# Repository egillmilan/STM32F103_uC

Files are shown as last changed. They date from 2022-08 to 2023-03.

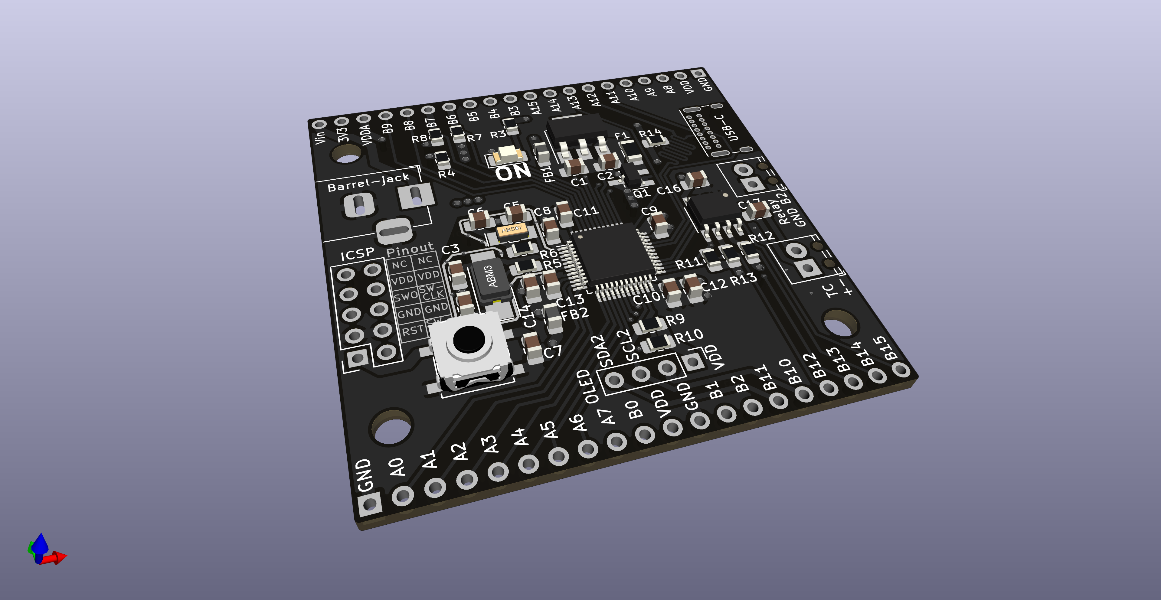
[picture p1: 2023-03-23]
STM32F103_uC_v1/images/STM32F103_uC_v1_1.png

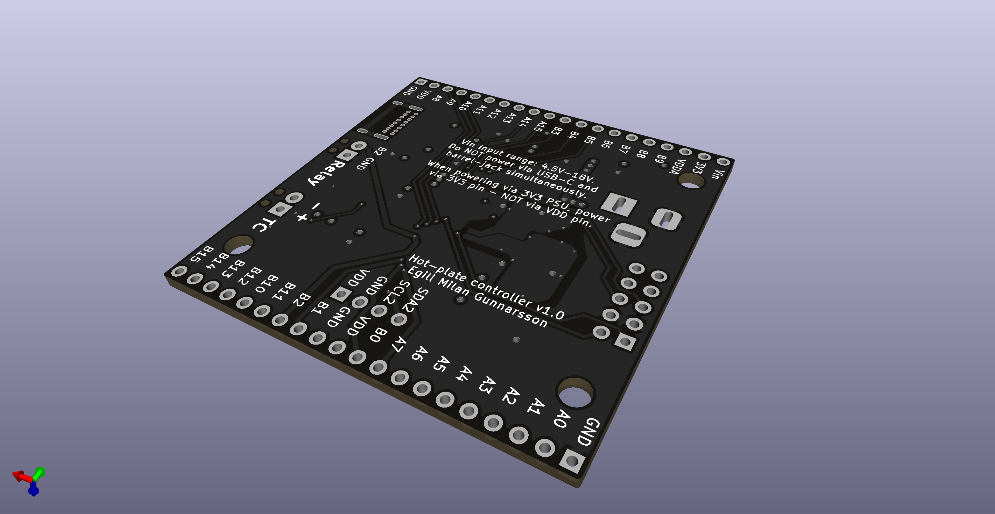
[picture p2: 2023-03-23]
STM32F103_uC_v1/images/STM32F103_uC_v1_2.png

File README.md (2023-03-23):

# STM32F103_uC
 A control board for a reflow hot plate project. The microcontroller being used is the STM32F103C8T6.

STM32F103_uC_v1_4
STM32F103_uC_v1_3
STM32F103_uC_v1_1
STM32F103_uC_v1_2

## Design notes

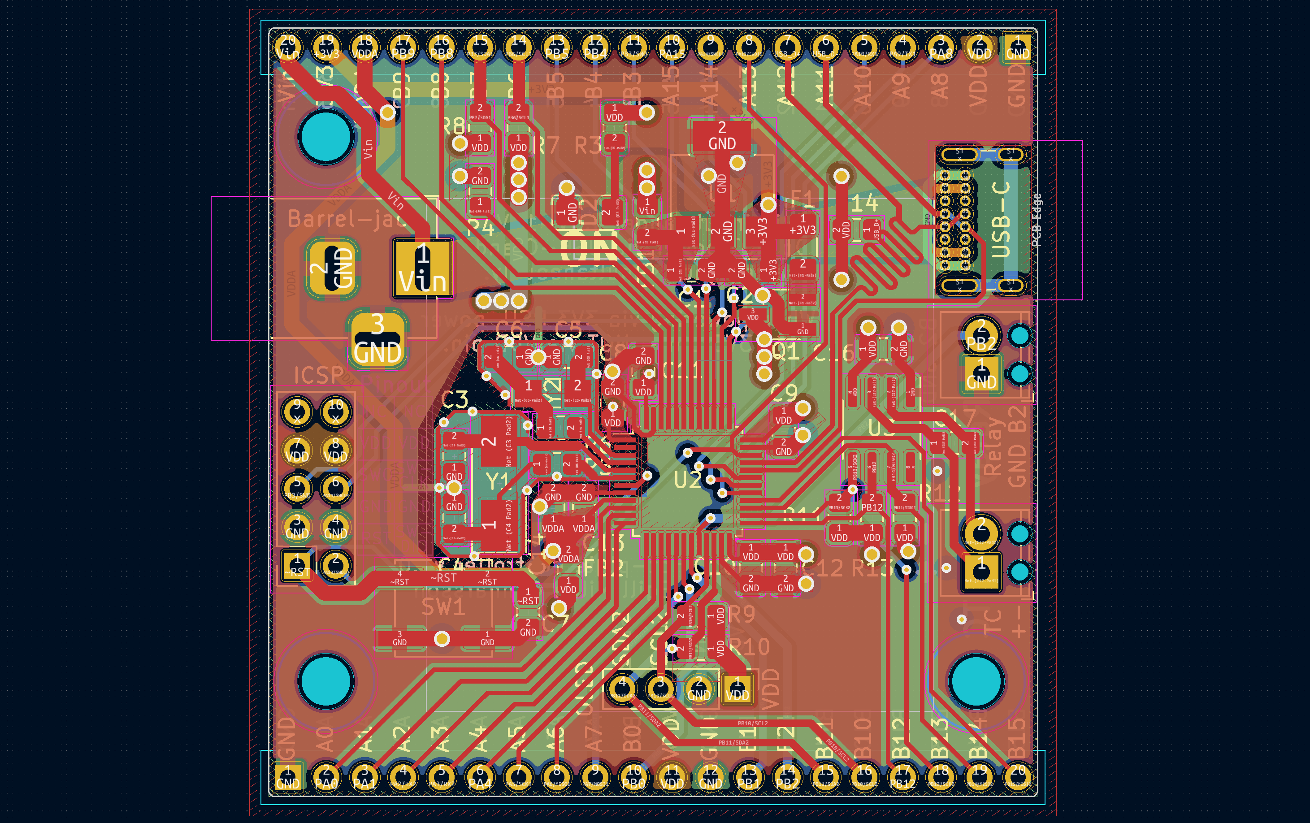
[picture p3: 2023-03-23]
STM32F103_uC_v1/images/STM32F103_uC_v1_3.png

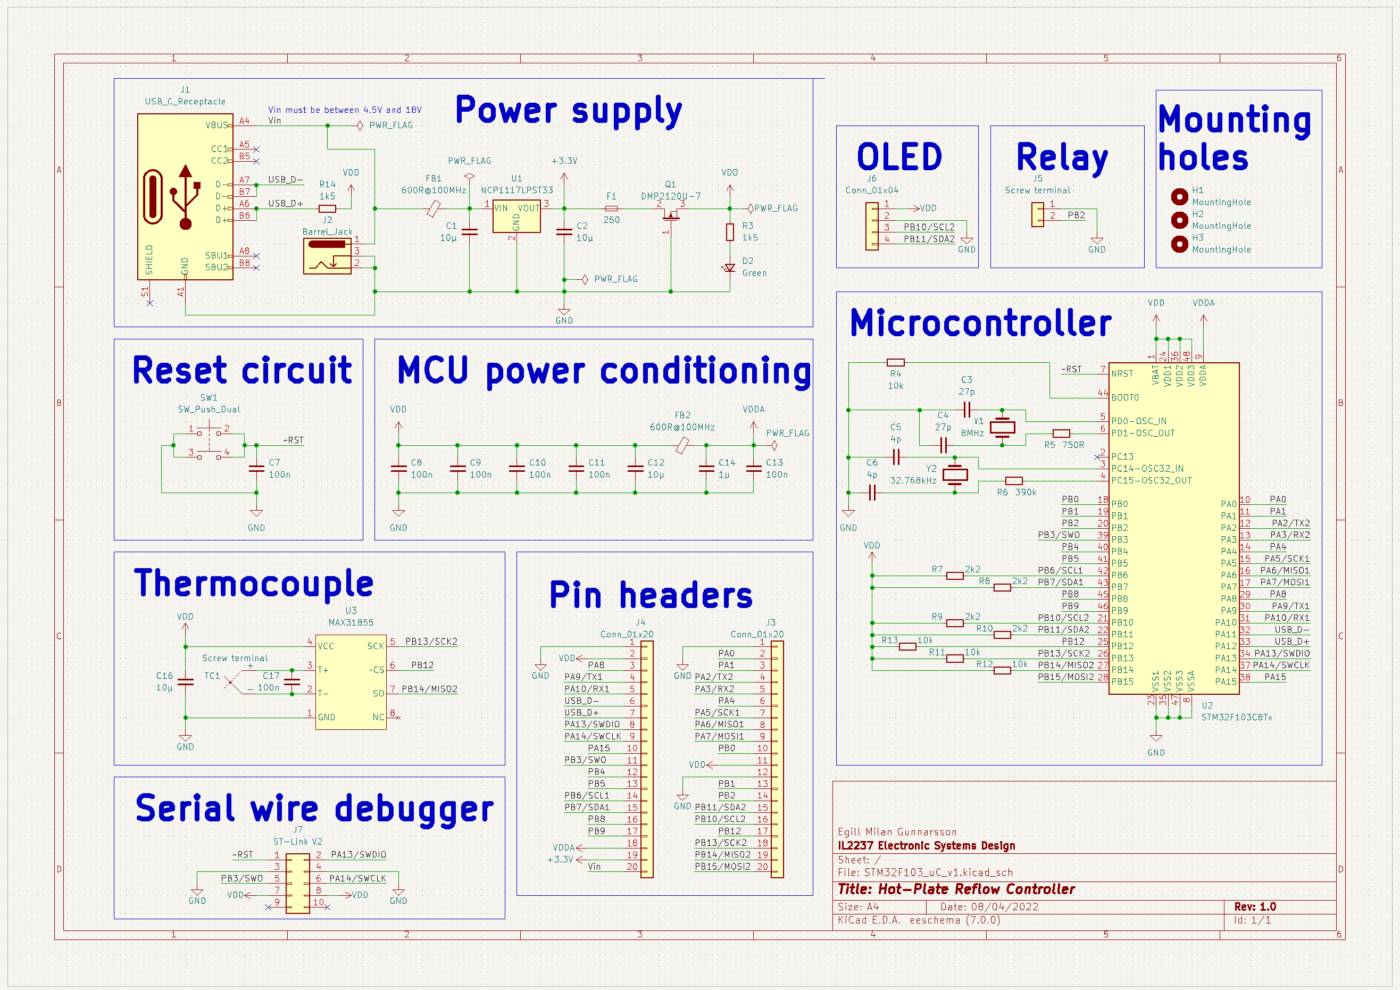
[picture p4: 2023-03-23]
STM32F103_uC_v1/images/STM32F103_uC_v1_4.png

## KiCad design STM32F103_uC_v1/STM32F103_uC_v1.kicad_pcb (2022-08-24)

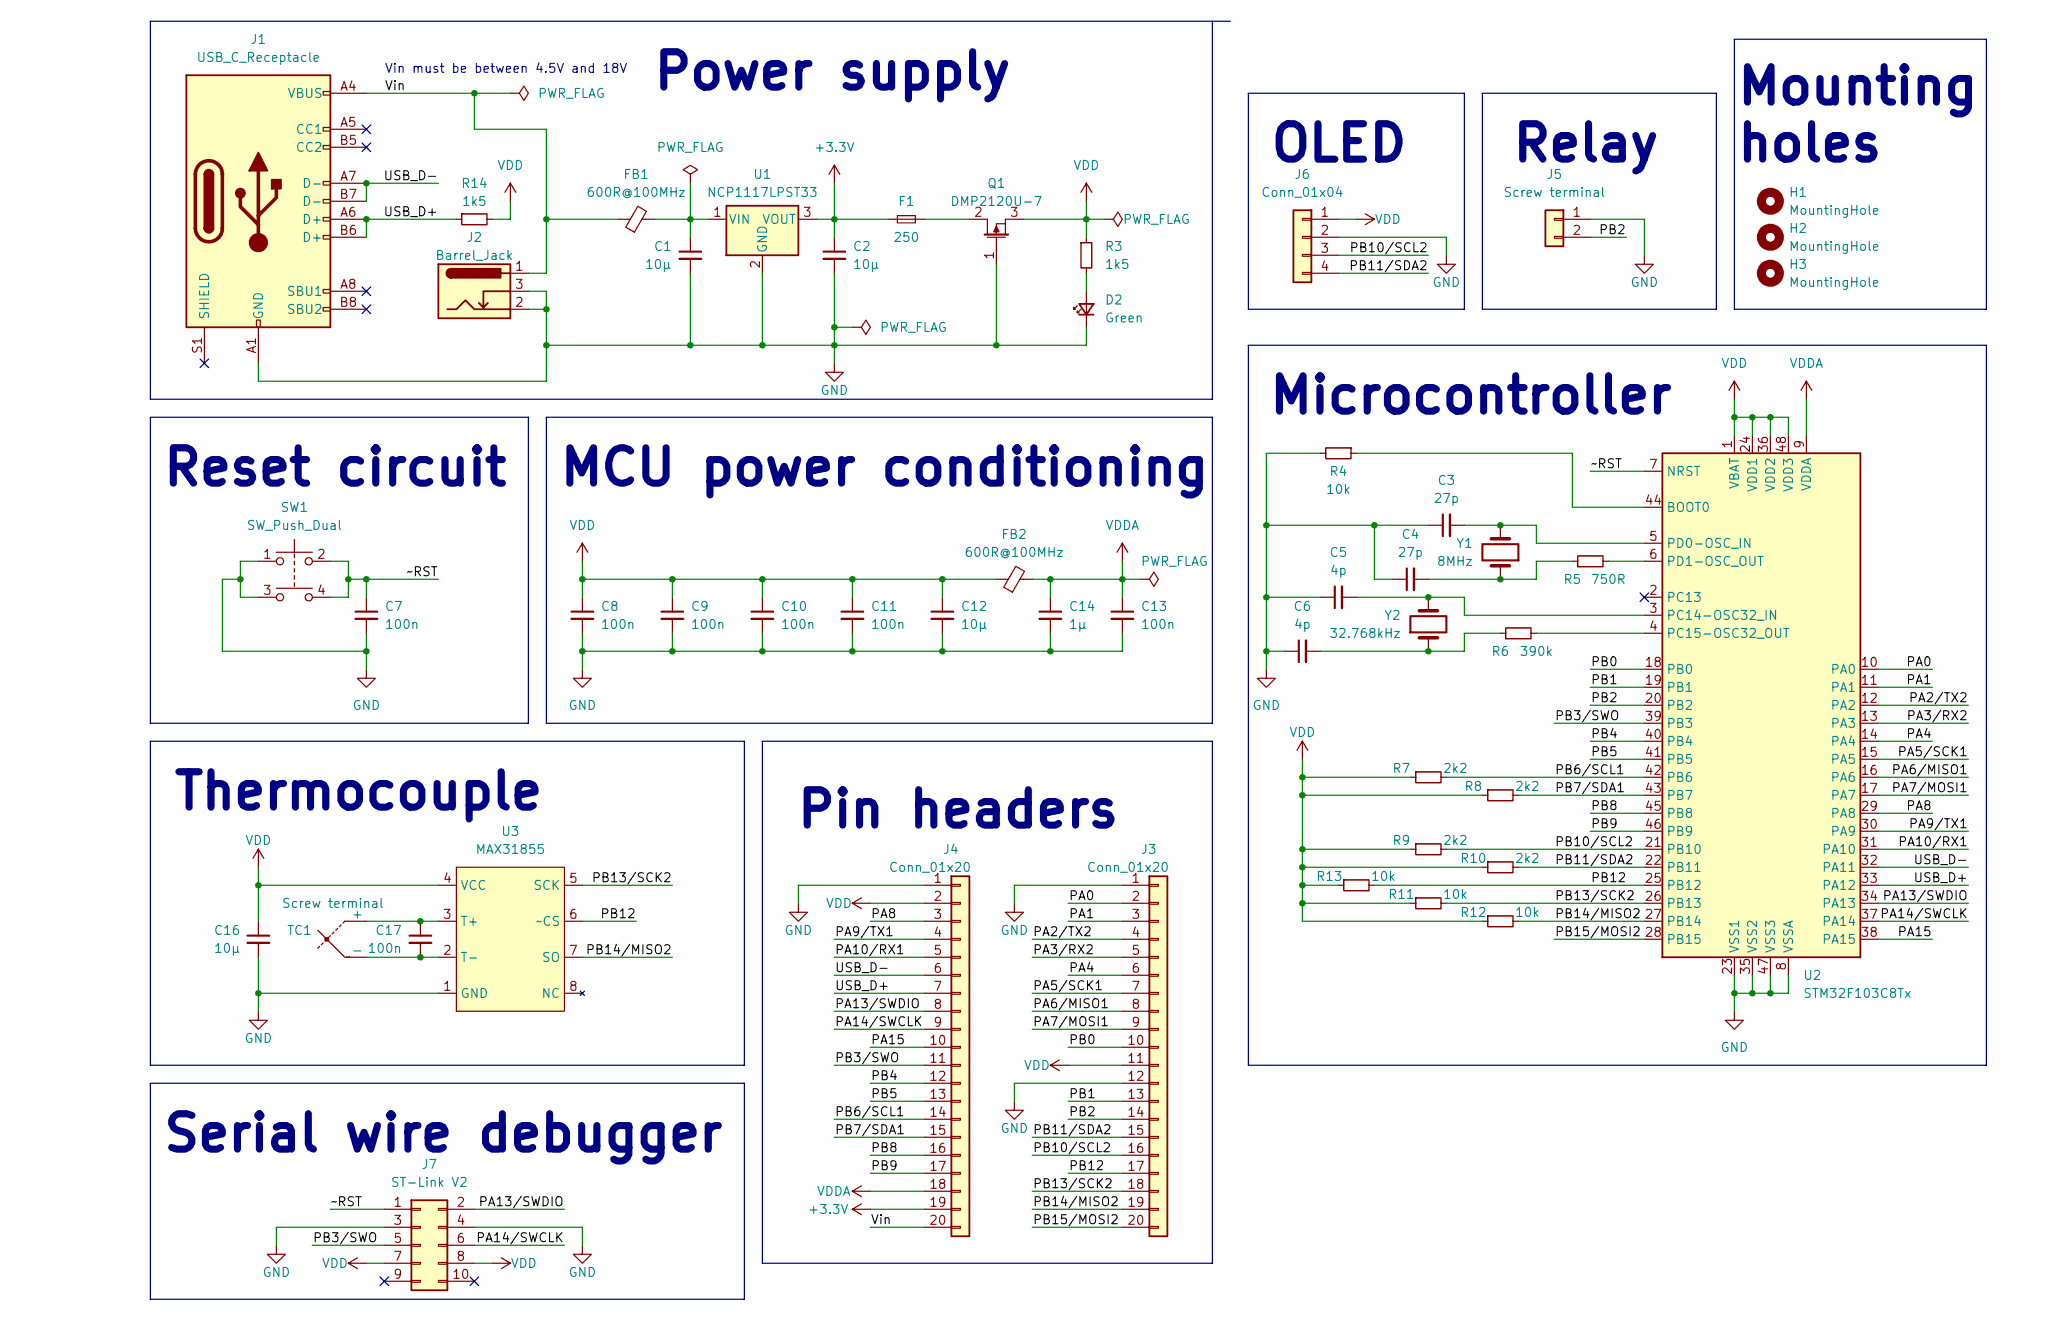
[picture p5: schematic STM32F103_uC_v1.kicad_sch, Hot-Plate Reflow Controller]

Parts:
C1, C2, C12, C16: 10µ; C_0805_2012Metric_Pad1.18x1.45mm_HandSolder
C3, C4: 27p; C_0805_2012Metric_Pad1.18x1.45mm_HandSolder
C5, C6: 4p; C_0805_2012Metric_Pad1.18x1.45mm_HandSolder
C7, C8, C9, C10, C11, C13, C17: 100n; C_0805_2012Metric_Pad1.18x1.45mm_HandSolder
C14: 1µ; C_0805_2012Metric_Pad1.18x1.45mm_HandSolder
D2: Green; LED_1206_3216Metric_Pad1.42x1.75mm_HandSolder
F1: 250; Fuse_1206_3216Metric_Pad1.42x1.75mm_HandSolder
FB1, FB2: 600R@100MHz; L_0805_2012Metric_Pad1.15x1.40mm_HandSolder
H1, H2, H3: MountingHole; MountingHole_3.2mm_M3
J1: USB_C_Receptacle; USB_C_Receptacle_GCT_USB4085
J2: Barrel_Jack; BarrelJack_Horizontal
J3, J4: Conn_01x20; PinHeader_1x20_P2.54mm_Vertical
J5: Screw terminal; TerminalBlock_Phoenix_MPT-0,5-2-2.54_1x02_P2.54mm_Horizontal
J6: Conn_01x04; 1.3_inch_OLED_IIC
J7: ST-Link V2; PinSocket_2x05_P2.54mm_Vertical
Q1: DMP2120U-7; SC-59_Handsoldering
R3, R14: 1k5; R_0805_2012Metric_Pad1.20x1.40mm_HandSolder
R4, R11, R12, R13: 10k; R_0805_2012Metric_Pad1.20x1.40mm_HandSolder
R5: 750R; R_0805_2012Metric_Pad1.20x1.40mm_HandSolder
R6: 390k; R_0805_2012Metric_Pad1.20x1.40mm_HandSolder
R7, R8, R9, R10: 2k2; R_0805_2012Metric_Pad1.20x1.40mm_HandSolder
SW1: SW_Push_Dual; SW_Push_1P1T_NO_CK_KSC6xxJ
TC1: Screw terminal; TerminalBlock_Phoenix_MPT-0,5-2-2.54_1x02_P2.54mm_Horizontal
U1: NCP1117LPST33; SOT-223-3_TabPin2
U2: STM32F103C8Tx; LQFP-48_7x7mm_P0.5mm
U3: MAX31855; SOIC-8_3.9x4.9mm_P1.27mm
Y1: 8MHz; Crystal_SMD_Abracon_ABM3-2Pin_5.0x3.2mm_HandSoldering
Y2: 32.768kHz; Crystal_SMD_MicroCrystal_CC7V-T1A-2Pin_3.2x1.5mm_HandSolder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

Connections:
+3V3: C2.1, F1.1, J4.19, U1.3 (VOUT)
/PA0: J3.2, U2.10 (PA0)
/PA1: J3.3, U2.11 (PA1)
/PA2/TX2: J3.4, U2.12 (PA2)
/PA3/RX2: J3.5, U2.13 (PA3)
/PA4: J3.6, U2.14 (PA4)
/PA5/SCK1: J3.7, U2.15 (PA5)
/PA6/MISO1: J3.8, U2.16 (PA6)
/PA7/MOSI1: J3.9, U2.17 (PA7)
/PA8: J4.3, U2.29 (PA8)
/PA9/TX1: J4.4, U2.30 (PA9)
/PA10/RX1: J4.5, U2.31 (PA10)
/PA13/SWDIO: J4.8, J7.2, U2.34 (PA13)
/PA14/SWCLK: J4.9, J7.6, U2.37 (PA14)
/PA15: J4.10, U2.38 (PA15)
/PB0: J3.10, U2.18 (PB0)
/PB1: J3.13, U2.19 (PB1)
/PB2: J3.14, J5.2, U2.20 (PB2)
/PB3/SWO: J4.11, J7.5, U2.39 (PB3)
/PB4: J4.12, U2.40 (PB4)
/PB5: J4.13, U2.41 (PB5)
/PB6/SCL1: J4.14, R7.2, U2.42 (PB6)
/PB7/SDA1: J4.15, R8.2, U2.43 (PB7)
/PB8: J4.16, U2.45 (PB8)
/PB9: J4.17, U2.46 (PB9)
/PB10/SCL2: J3.16, J6.3, R9.2, U2.21 (PB10)
/PB11/SDA2: J3.15, J6.4, R10.2, U2.22 (PB11)
/PB12: J3.17, R13.2, U2.25 (PB12), U3.6 (~CS)
/PB13/SCK2: J3.18, R11.2, U2.26 (PB13), U3.5 (SCK)
/PB14/MISO2: J3.19, R12.2, U2.27 (PB14), U3.7 (SO)
/PB15/MOSI2: J3.20, U2.28 (PB15)
/USB_D+: J1.A6 (D+), J1.B6 (D+), J4.7, R14.1, U2.33 (PA12)
/USB_D-: J1.A7 (D-), J1.B7 (D-), J4.6, U2.32 (PA11)
/Vin: FB1.1, J1.A4 (VBUS), J1.A9 (VBUS), J1.B4 (VBUS), J1.B9 (VBUS), J2.1, J4.20
/~RST: C7.1, J7.1, SW1.2, SW1.4, U2.7 (NRST)
GND: C1.2, C2.2, C3.1, C4.1, C5.1, C6.1, C7.2, C8.2, C9.2, C10.2, C11.2, C12.2, C13.2, C14.2, C16.2, D2.1 (K), J1.A1 (GND), J1.A12 (GND), J1.B1 (GND), J1.B12 (GND), J2.2, J2.3, J3.1, J3.12, J4.1, J5.1, J6.2, J7.3, J7.4, Q1.1, R4.2, SW1.1, SW1.3, U1.2 (GND), U2.8 (VSSA), U2.23 (VSS1), U2.35 (VSS2), U2.47 (VSS3), U3.1 (GND)
unnamed: C1.1, FB1.2, U1.1 (VIN)
unnamed: C3.2, U2.5 (PD0-OSC_IN), Y1.2
unnamed: C4.2, R5.1, Y1.1
unnamed: C5.2, U2.3 (PC14-OSC32_IN), Y2.2
unnamed: C6.2, R6.1, Y2.1
unnamed: C17.1, TC1.1 (+), U3.3 (T+)
unnamed: C17.2, TC1.2 (-), U3.2 (T-)
unnamed: D2.2 (A), R3.2
unnamed: F1.2, Q1.2
unnamed: R4.1, U2.44 (BOOT0)
unnamed: R5.2, U2.6 (PD1-OSC_OUT)
unnamed: R6.2, U2.4 (PC15-OSC32_OUT)
VDD: C8.1, C9.1, C10.1, C11.1, C12.1, C16.1, FB2.1, J3.11, J4.2, J6.1, J7.7, J7.8, Q1.3, R3.1, R7.1, R8.1, R9.1, R10.1, R11.1, R12.1, R13.1, R14.2, U2.1 (VBAT), U2.24 (VDD1), U2.36 (VDD2), U2.48 (VDD3), U3.4 (VCC)
VDDA: C13.1, C14.1, FB2.2, J4.18, U2.9 (VDDA)

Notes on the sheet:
Pin headers
Reset circuit
MCU power conditioning
Vin must be between 4.5V and 18V
OLED
Power supply
Microcontroller
Relay
Serial wire debugger
Thermocouple
Mounting holes

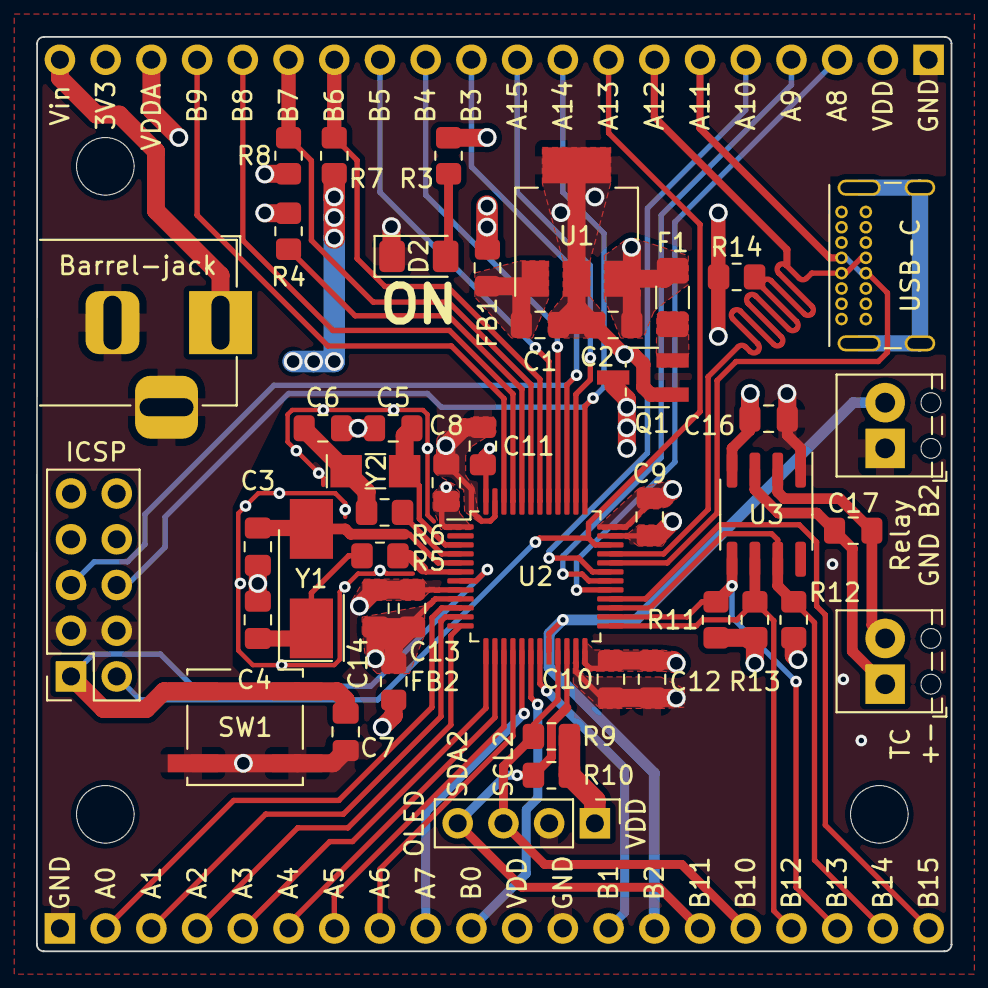
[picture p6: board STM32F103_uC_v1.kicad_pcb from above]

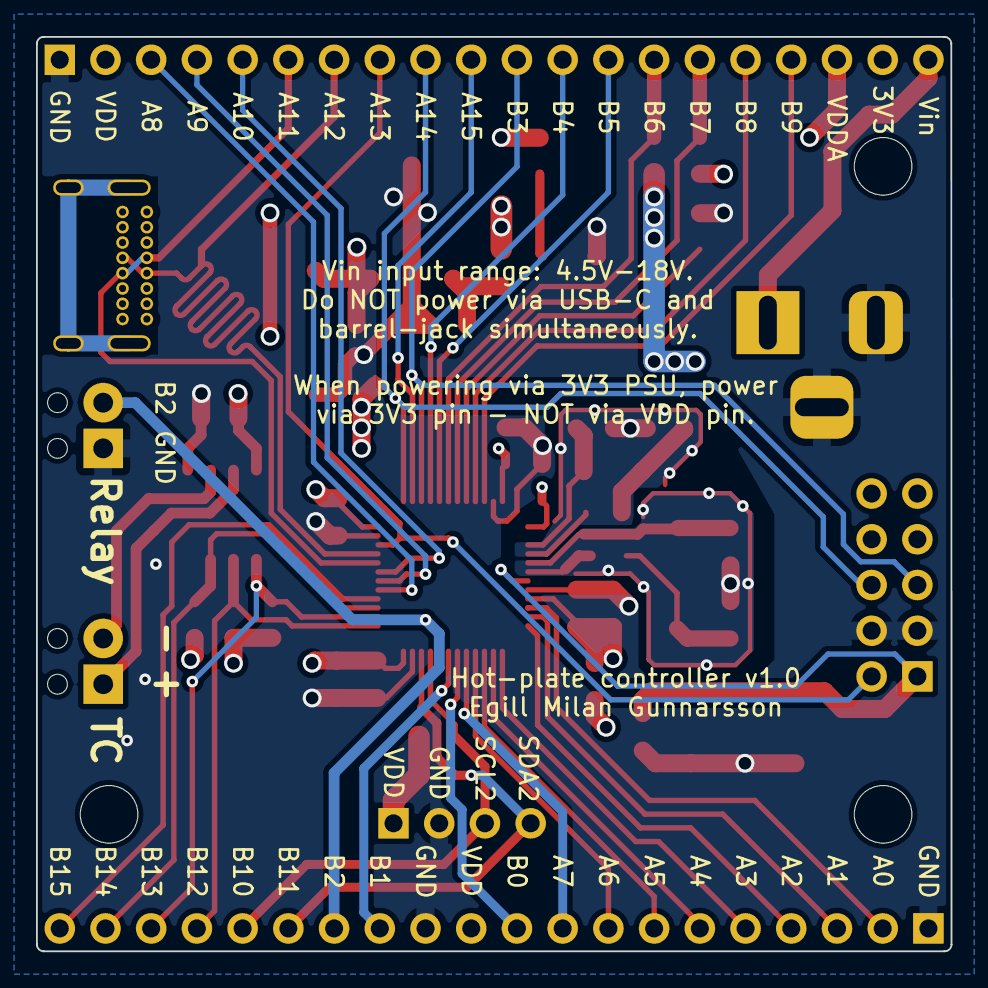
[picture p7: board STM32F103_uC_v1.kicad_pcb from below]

Board: 4 copper layers, 50.8 x 50.8 mm, 50 parts (2 on the bottom side), 50 nets.

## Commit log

2022-04-07 100nF -> 10nF
    [STM32F103_uC_v1.kicad_sch]
2022-04-11 Schematic additions
    [STM32F103_uC_v1.kicad_sch]
2022-04-12 Small schematic changes
2022-05-09 Version 1.0
    [STM32F103_uC_v1.kicad_pcb, STM32F103_uC_v1.kicad_sch]
2022-05-20 Finishing touches
    [STM32F103_uC_v1.kicad_pcb, STM32F103_uC_v1.kicad_sch]
2022-05-20 Added Gerbers
    [STM32F103_uC_v1-B_Cu.gbl, STM32F103_uC_v1-B_Mask.gbs, STM32F103_uC_v1-B_Silkscreen.gbo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]
2022-08-24 Fixed LDO pinout
    [STM32F103_uC_v1.kicad_pcb]
